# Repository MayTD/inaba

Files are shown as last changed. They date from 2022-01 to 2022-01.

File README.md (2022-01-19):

# Inaba 
An open source 40% keyboard with a rotary encoder. Loosely designed by retro TVs and inspired by Persona 4's Midnight Channel.

> [The Midnight Channel (マヨナカテレビ, Mayonaka Terebi), also known as the TV World and Mayonaka TV, is a recurring term in Persona 4. The stuff of urban legends, its existence is spread through the town of Inaba through rumors.](https://megamitensei.fandom.com/wiki/Midnight_Channel)

## Assembly
Components needed for the pcb to be functional or completed.
| Part Number | Qty | Description | Component Reference |
| - | - | - | - |
| ATMEGA32U4-AU | 1 | IC MCU 8BIT 32KB FLASH 44TQFP | U1 |
| PRTR5V0U2X,215 | 1 | TVS DIODE 5.5VWM SOT143B | U2 |
| USB4105-GF-A | 1 | USB-C (USB TYPE-C) USB 2.0 Receptacle | J1 |
| 1N4148W-HE3-08 | 50 | DIODE GEN PURP 75V 150MA SOD123 | D1-D50 |
| WS2812B 5050 RGB LED | 1 | 5mm x 5mm RGB LED | LED1 |
| CX3225SB16000D0GZJC1 | 1 | CRYSTAL 16.0000MHZ 8PF SMD | Y1 |
| ERA-6AEB103V | 2 | RES 10K OHM 0.1% 1/8W 0805 | R1, R4 |
| ERJ-6GEYJ220V | 2 | RES SMD 22 OHM 5% 1/8W 0805 | R2-R3 |
| RC2012J512CS |2| RES SMD 5.1K OHM 5% 1/8W 0805 | R5-R6 |
| CRGCQ0805F330R | 1 | RES 330 OHM 1% 1/8W 0805 | R7 |
| CL21B105KAFNNNE | 1 | CAP CER 1UF 25V X7R 0805 | C1 |
| CL21B104MBCNNNC | 3 | CAP CER 0.1UF 50V X7R 0805 | C2-C4 |
| CL21A106KOQNNNG | 1 | CAP CER 10UF 16V X5R 0805 | C5 |
| CL21C220JB61PNC | 2 | CAP CER 22PF 50V C0G/NP0 0805 | C6-C7 |
| B3U-1000P | 1  | SWITCH TACTILE SPST-NO 0.05A 12V | SW1 |
| 0ZCJ0050AF2E | 1  | PTC RESET FUSE 24V 500MA 1206 | F1 |

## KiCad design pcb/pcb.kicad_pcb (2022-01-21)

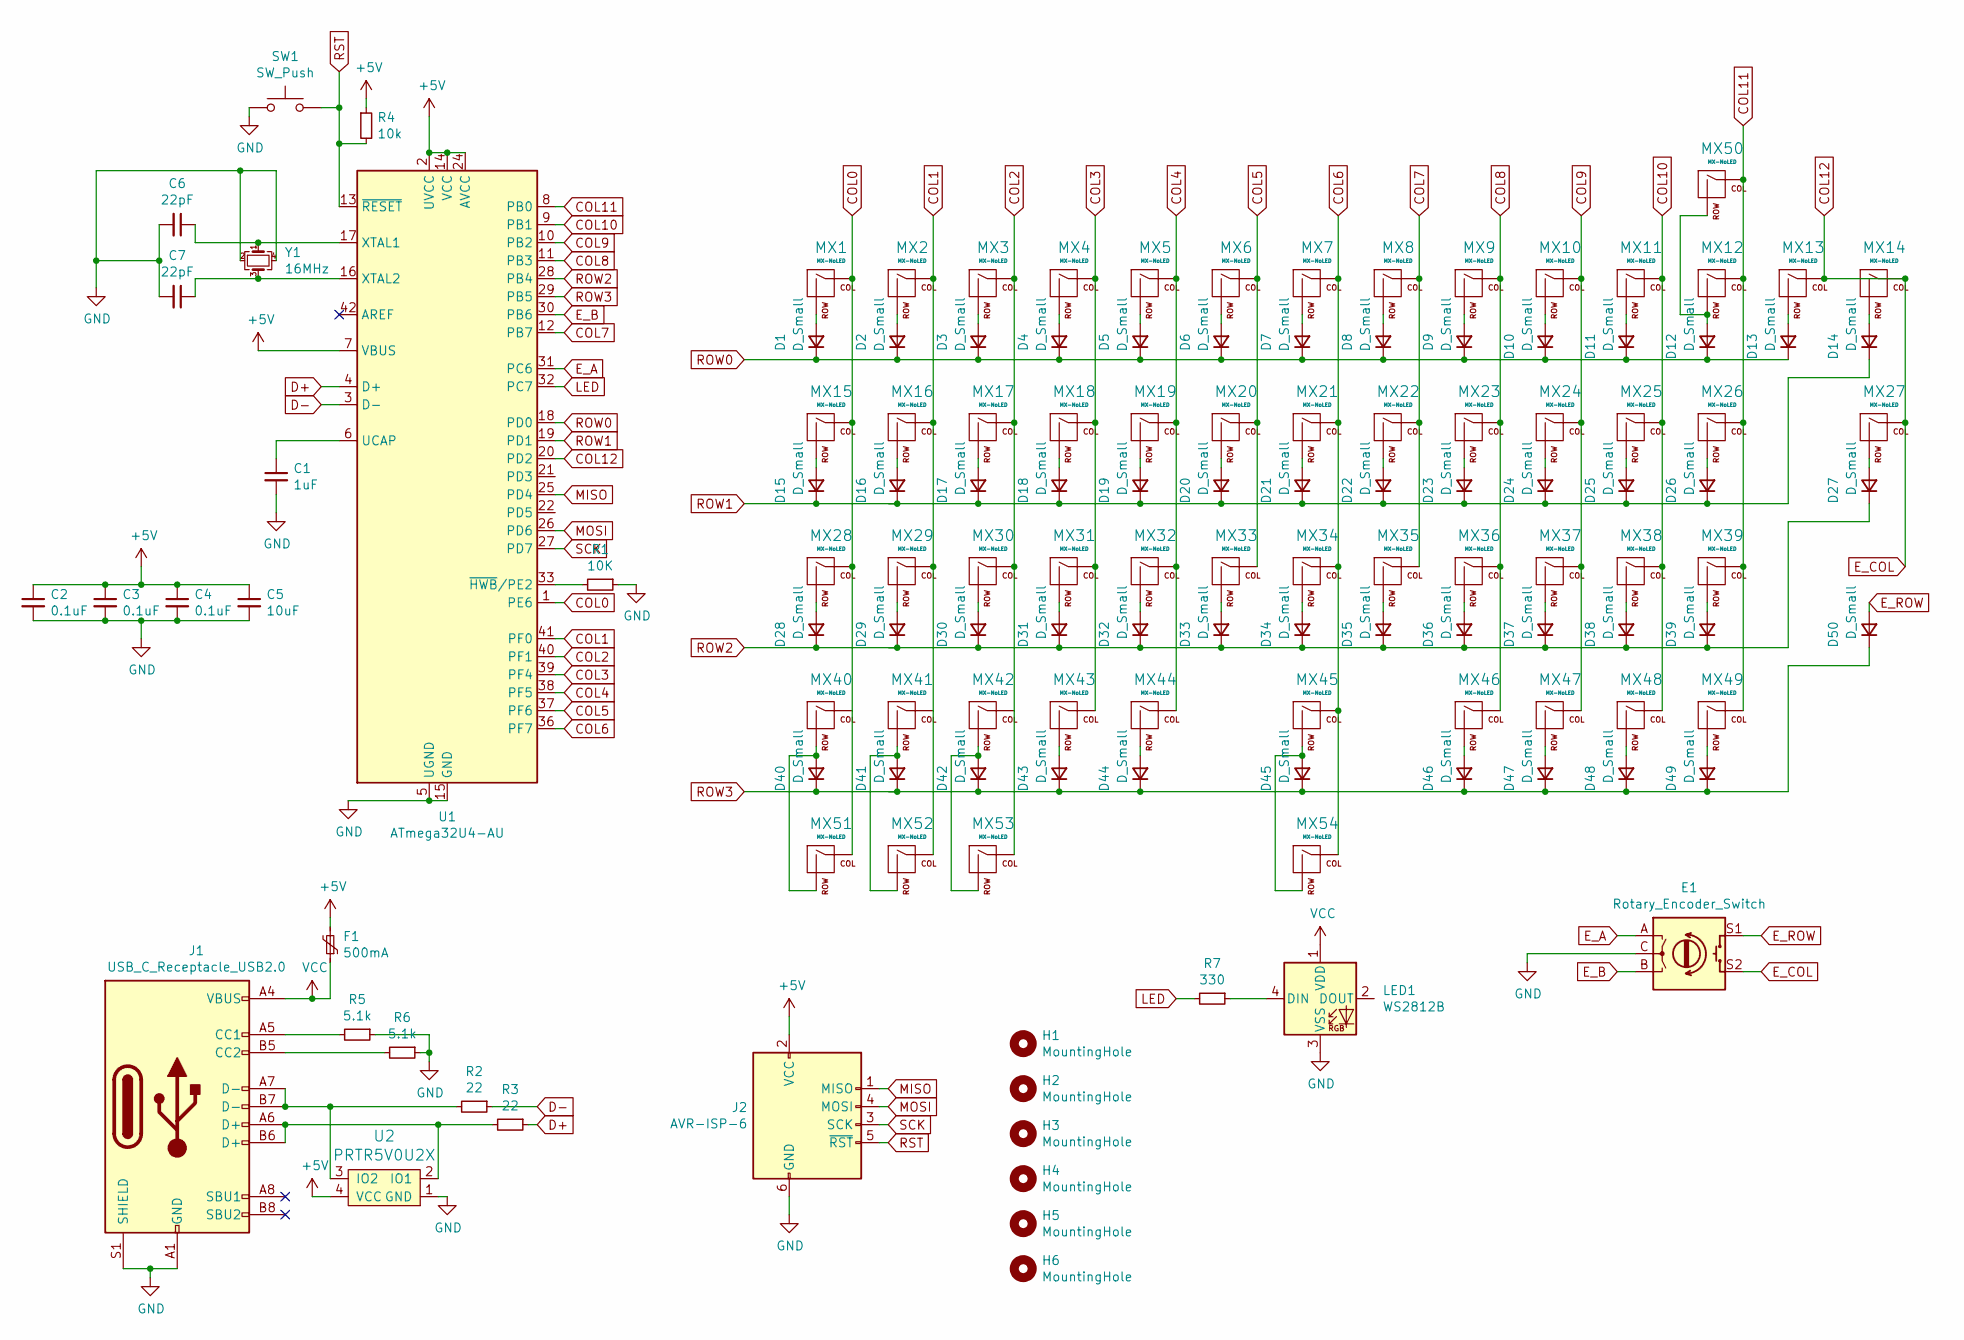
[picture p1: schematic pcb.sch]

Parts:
C1: 1uF; C_0805_2012Metric
C2, C3, C4: 0.1uF; C_0805_2012Metric
C5: 10uF; C_0805_2012Metric
C6, C7: 22pF; C_0805_2012Metric
D1, D2, D3, D4, D5, D6, D7, D8, D9, D10, D11, D12, D13, D14, D15, D16, D17, D18, D19, D20, D21, D22, D23, D24, D25, D26, D27, D28, D29, D30, D31, D32, D33, D34, D35, D36, D37, D38, D39, D40, D41, D42, D43, D44, D45, D46, D47, D48, D49, D50: D_Small; D_SOD-123
E1: Rotary_Encoder_Switch; RotaryEncoder_Alps_EC11E-Switch_Vertical_H20mm_CircularMoun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
F1: 500mA; Fuse_1206_3216Metric
H1, H2, H3, H4, H5, H6: MountingHole; MountingHole_2.2mm_M2_Pad
J1: USB_C_Receptacle_USB2.0; USB_C_Receptacle_Palconn_UTC16-G
J2: AVR-ISP-6; Reset_Pretty-Mask
LED1: WS2812B; LED_WS2812B_PLCC4_5.0x5.0mm_P3.2mm
MX1, MX2, MX3, MX4, MX5, MX6, MX7, MX8, MX9, MX10, MX11, MX12, MX13, MX14, MX16, MX17, MX18, MX19, MX20, MX21, MX22, MX23, MX24, MX25, MX27, MX29, MX30, MX31, MX32, MX33, MX34, MX35, MX36, MX37, MX38, MX40, MX41, MX42, MX43, MX46, MX47, MX48, MX49: MX-NoLED; MX-1U-NoLED
MX15, MX26: MX-NoLED; MX-1.5U-NoLED
MX28: MX-NoLED; MX-1.75U-NoLED
MX39, MX51, MX52, MX53: MX-NoLED; MX-1.25U-NoLED
MX44: MX-NoLED; MX-2.25U-ReversedStabilizers-NoLED
MX45: MX-NoLED; MX-2.75U-ReversedStabilizers-NoLED
MX50: MX-NoLED; MX-2U-NoLED
MX54: MX-NoLED; MX-6U-Centered-ReversedStabilizers-NoLED
R1: 10K; R_0805_2012Metric
R2, R3: 22; R_0805_2012Metric
R4: 10k; R_0805_2012Metric
R5, R6: 5.1k; R_0805_2012Metric
R7: 330; R_0805_2012Metric
SW1: SW_Push; SW_SPST_B3U-1000P-B
U1: ATmega32U4-AU; TQFP-44_10x10mm_P0.8mm
U2: PRTR5V0U2X; SOT143B
Y1: 16MHz; Crystal_SMD_3225-4Pin_3.2x2.5mm

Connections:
+5V: C2.1, C3.1, C4.1, C5.1, F1.2, J2.2 (VCC), R4.1, U1.2 (UVCC), U1.7 (VBUS), U1.14 (VCC), U1.24 (AVCC), U1.34 (VCC), U1.44 (AVCC), U2.4 (VCC)
COL0: MX1.1 (COL), MX15.1 (COL), MX28.1 (COL), MX40.1 (COL), MX51.1 (COL), U1.1 (PE6)
COL1: MX2.1 (COL), MX16.1 (COL), MX29.1 (COL), MX41.1 (COL), MX52.1 (COL), U1.41 (PF0)
COL2: MX3.1 (COL), MX17.1 (COL), MX30.1 (COL), MX42.1 (COL), MX53.1 (COL), U1.40 (PF1)
COL3: MX4.1 (COL), MX18.1 (COL), MX31.1 (COL), MX43.1 (COL), U1.39 (PF4)
COL4: MX5.1 (COL), MX19.1 (COL), MX32.1 (COL), MX44.1 (COL), U1.38 (PF5)
COL5: MX6.1 (COL), MX20.1 (COL), MX33.1 (COL), U1.37 (PF6)
COL6: MX7.1 (COL), MX21.1 (COL), MX34.1 (COL), MX45.1 (COL), MX54.1 (COL), U1.36 (PF7)
COL7: MX8.1 (COL), MX22.1 (COL), MX35.1 (COL), U1.12 (PB7)
COL8: MX9.1 (COL), MX23.1 (COL), MX36.1 (COL), MX46.1 (COL), U1.11 (PB3)
COL9: MX10.1 (COL), MX24.1 (COL), MX37.1 (COL), MX47.1 (COL), U1.10 (PB2)
COL10: MX11.1 (COL), MX25.1 (COL), MX38.1 (COL), MX48.1 (COL), U1.9 (PB1)
COL11: MX12.1 (COL), MX26.1 (COL), MX39.1 (COL), MX49.1 (COL), MX50.1 (COL), U1.8 (PB0)
COL12: E1.S2, MX13.1 (COL), MX14.1 (COL), MX27.1 (COL), U1.20 (PD2)
D+: R3.1, U1.4 (D+)
D-: R2.1, U1.3 (D-)
E_A: E1.A, U1.31 (PC6)
E_B: E1.B, U1.30 (PB6)
E_ROW: D50.2 (A), E1.S1
GND: C1.2, C2.2, C3.2, C4.2, C5.2, C6.2, C7.2, E1.C, J1.A1 (GND), J1.A12 (GND), J1.B1 (GND), J1.B12 (GND), J1.S1 (SHIELD), J2.6 (GND), LED1.3 (VSS), R1.1, R5.1, R6.1, SW1.1, U1.5 (UGND), U1.15 (GND), U1.23 (GND), U1.35 (GND), U1.43 (GND), U2.1 (GND), Y1.2, Y1.4
LED: R7.2, U1.32 (PC7)
MISO: J2.1 (MISO), U1.25 (PD4)
MOSI: J2.4 (MOSI), U1.26 (PD6)
unnamed: C1.1, U1.6 (UCAP)
unnamed: C6.1, U1.17 (XTAL1), Y1.1
unnamed: C7.1, U1.16 (XTAL2), Y1.3
unnamed: D1.2 (A), MX1.2 (ROW)
unnamed: D2.2 (A), MX2.2 (ROW)
unnamed: D3.2 (A), MX3.2 (ROW)
unnamed: D4.2 (A), MX4.2 (ROW)
unnamed: D5.2 (A), MX5.2 (ROW)
unnamed: D6.2 (A), MX6.2 (ROW)
unnamed: D7.2 (A), MX7.2 (ROW)
unnamed: D8.2 (A), MX8.2 (ROW)
unnamed: D9.2 (A), MX9.2 (ROW)
unnamed: D10.2 (A), MX10.2 (ROW)
unnamed: D11.2 (A), MX11.2 (ROW)
unnamed: D12.2 (A), MX12.2 (ROW), MX50.2 (ROW)
unnamed: D13.2 (A), MX13.2 (ROW)
unnamed: D14.2 (A), MX14.2 (ROW)
unnamed: D15.2 (A), MX15.2 (ROW)
unnamed: D16.2 (A), MX16.2 (ROW)
unnamed: D17.2 (A), MX17.2 (ROW)
unnamed: D18.2 (A), MX18.2 (ROW)
unnamed: D19.2 (A), MX19.2 (ROW)
unnamed: D20.2 (A), MX20.2 (ROW)
unnamed: D21.2 (A), MX21.2 (ROW)
unnamed: D22.2 (A), MX22.2 (ROW)
unnamed: D23.2 (A), MX23.2 (ROW)
unnamed: D24.2 (A), MX24.2 (ROW)
unnamed: D25.2 (A), MX25.2 (ROW)
unnamed: D26.2 (A), MX26.2 (ROW)
unnamed: D27.2 (A), MX27.2 (ROW)
unnamed: D28.2 (A), MX28.2 (ROW)
unnamed: D29.2 (A), MX29.2 (ROW)
unnamed: D30.2 (A), MX30.2 (ROW)
unnamed: D31.2 (A), MX31.2 (ROW)
unnamed: D32.2 (A), MX32.2 (ROW)
unnamed: D33.2 (A), MX33.2 (ROW)
unnamed: D34.2 (A), MX34.2 (ROW)
unnamed: D35.2 (A), MX35.2 (ROW)
unnamed: D36.2 (A), MX36.2 (ROW)
unnamed: D37.2 (A), MX37.2 (ROW)
unnamed: D38.2 (A), MX38.2 (ROW)
unnamed: D39.2 (A), MX39.2 (ROW)
unnamed: D40.2 (A), MX40.2 (ROW), MX51.2 (ROW)
unnamed: D41.2 (A), MX41.2 (ROW), MX52.2 (ROW)
unnamed: D42.2 (A), MX42.2 (ROW), MX53.2 (ROW)
unnamed: D43.2 (A), MX43.2 (ROW)
unnamed: D44.2 (A), MX44.2 (ROW)
unnamed: D45.2 (A), MX45.2 (ROW), MX54.2 (ROW)
unnamed: D46.2 (A), MX46.2 (ROW)
unnamed: D47.2 (A), MX47.2 (ROW)
unnamed: D48.2 (A), MX48.2 (ROW)
unnamed: D49.2 (A), MX49.2 (ROW)
unnamed: J1.A5 (CC1), R5.2
unnamed: J1.A6 (D+), J1.B6 (D+), R3.2, U2.2 (IO1)
unnamed: J1.A7 (D-), J1.B7 (D-), R2.2, U2.3 (IO2)
unnamed: J1.B5 (CC2), R6.2
unnamed: LED1.4 (DIN), R7.1
unnamed: R1.2, U1.33 (~HWB~/PE2)
ROW0: D1.1 (K), D2.1 (K), D3.1 (K), D4.1 (K), D5.1 (K), D6.1 (K), D7.1 (K), D8.1 (K), D9.1 (K), D10.1 (K), D11.1 (K), D12.1 (K), D13.1 (K), U1.18 (PD0)
ROW1: D14.1 (K), D15.1 (K), D16.1 (K), D17.1 (K), D18.1 (K), D19.1 (K), D20.1 (K), D21.1 (K), D22.1 (K), D23.1 (K), D24.1 (K), D25.1 (K), D26.1 (K), U1.19 (PD1)
ROW2: D27.1 (K), D28.1 (K), D29.1 (K), D30.1 (K), D31.1 (K), D32.1 (K), D33.1 (K), D34.1 (K), D35.1 (K), D36.1 (K), D37.1 (K), D38.1 (K), D39.1 (K), U1.28 (PB4)
ROW3: D40.1 (K), D41.1 (K), D42.1 (K), D43.1 (K), D44.1 (K), D45.1 (K), D46.1 (K), D47.1 (K), D48.1 (K), D49.1 (K), D50.1 (K), U1.29 (PB5)
RST: J2.5 (~RST), R4.2, SW1.2, U1.13 (~RESET)
SCK: J2.3 (SCK), U1.27 (PD7)
VCC: F1.1, J1.A4 (VBUS), J1.A9 (VBUS), J1.B4 (VBUS), J1.B9 (VBUS), LED1.1 (VDD)

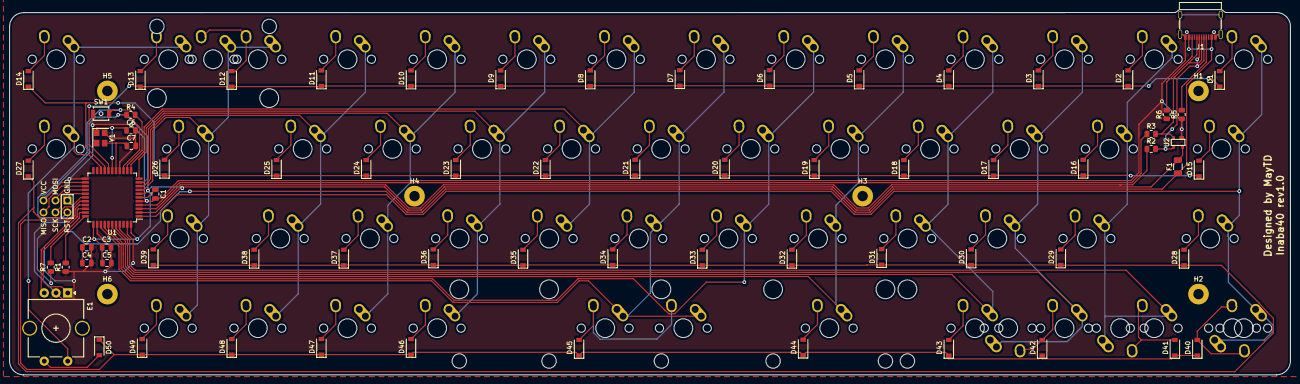
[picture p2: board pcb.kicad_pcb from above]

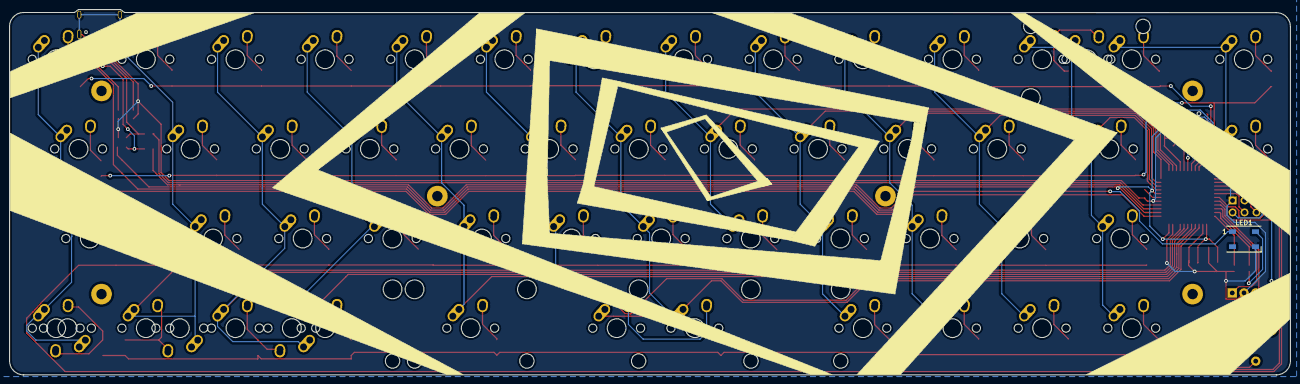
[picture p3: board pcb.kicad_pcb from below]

Board: 2 copper layers, 272.3 x 77.6 mm, 133 parts (55 on the bottom side), 88 nets.

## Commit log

2021-12-03 add footprint libs
    [pcb.kicad_pcb, pcb.sch]
2021-12-05 set up mcu and pcb
    [pcb.sch]
2021-12-06 set up switch matrix
    [pcb.sch]
2021-12-11 assign footprints
    [pcb.sch]
2021-12-12 add isp footprints
    [pcb.sch]
2021-12-12 iso mask footprint
    [pcb.sch]
2021-12-13 change iscp mask footprint
    [pcb.sch]
2021-12-31 route tracks
    [pcb.sch]
2022-01-04 create bottom plate
    [bottom.kicad_pcb, bottom.sch]
2022-01-05 add mounting holes to sch
    [bottom.kicad_pcb, bottom.sch]
2022-01-05 correct spacebar placements
    [pcb.kicad_pcb, pcb.sch]
2022-01-06 flip stabs on space
    [pcb.kicad_pcb]
2022-01-06 3mm outer spacing
    [bottom.kicad_pcb, pcb.kicad_pcb, pcb.sch]
2022-01-07 center isp and reroute tracks
    [pcb.kicad_pcb, pcb.sch]
2022-01-08 add LED and reshape width of macros spacer
    [pcb.kicad_pcb, pcb.sch]
2022-01-08 gnd zone fill
    [bottom.kicad_pcb, pcb.kicad_pcb]
2022-01-09 create plate
    [plate.kicad_pcb, plate.sch]
2022-01-09 add silkscreen design to pcb
    [pcb.kicad_pcb]
2022-01-15 move mounting holes and flip silk screen on pcb
    [bottom.kicad_pcb, pcb.kicad_pcb]
2022-01-19 include fuse in assembly component list
2022-01-19 create gerber files
    [bottom-B_Cu.gbr, bottom-B_Mask.gbr, bottom-B_Paste.gbr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]
2022-01-20 regenerate gerber
    [bottom-B_Cu.gbl, bottom-B_Mask.gbs, bottom-B_Paste.gbp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]
2022-01-21 regenerate gerber removing x2 option
    [pcb-B_Cu.gbl, pcb-B_Mask.gbs, pcb-B_Paste.gbp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]
2022-02-25 create gerber zips
    [plate-B_Cu.gbl, plate-B_Mask.gbs, plate-B_Paste.gbp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]
